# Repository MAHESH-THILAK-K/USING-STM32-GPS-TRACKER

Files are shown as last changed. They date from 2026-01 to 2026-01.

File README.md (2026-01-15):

# 📌 Project Overview

STM32-GPS-TRACKER is a compact, reliable, and industry-oriented GPS tracking system built around an **STM32 microcontroller** and the **SIM808 GSM/GPS module**. The system enables **real-time location tracking** and **cellular data transmission** for IoT and telemetry applications such as vehicle tracking, asset monitoring, and remote sensing.

The schematic and PCB are designed with **strong power integrity, EMI control, and manufacturability**, targeting a **4-layer PCB** suitable for real-world deployment.

---

## 🧩 System Architecture

| Block | Description |
| --- | --- |
| Power Input & Protection | Accepts 12 V input with fuse and surge protection |
| DC-DC Regulation | High-efficiency buck converter generates stable 3.3 V |
| Main Controller | STM32 microcontroller manages system logic |
| Communication Module | SIM808 provides GSM + GPS functionality |
| SIM Interface | SIM card socket with ESD protection |
| RF Section | U.FL connectors for GSM and GPS antennas |
| User Interface | Push buttons and status LEDs |
| Debug & Expansion | SWD and header pins for programming and I/O |

---

## 🔧 Core Controller – STM32 MCU

| Feature | Description |
| --- | --- |
| MCU | STM32 (ARM Cortex-M0 series) |
| Operating Voltage | 3.3 V |
| Clock Source | External crystal oscillator  |
| Programming | SWD (SWDIO, SWCLK, NRST) |
| Communication | UART interface to SIM808 |
| Control Signals | SIM808 PWRKEY, RESET |
| Indicators | Status LEDs via GPIO |

The STM32 acts as the **central controller**, handling GSM commands, GPS data processing, and system coordination.

---

## 📡 GSM/GPS Communication – SIM808

| Feature | Description |
| --- | --- |
| Module | SIM808 GSM + GPS |
| GSM | Cellular data communication |
| GPS | Satellite-based positioning |
| Interface | UART (TX/RX) |
| Control | Dedicated PWRKEY and RESET lines |
| Antennas  | Separate GSM and GPS U.FL connectors |

The SIM808 enables **accurate positioning** and **wide-area data transmission**, making the system suitable for mobile and remote applications.

---

## 🔋 Power Design

| Feature | Description |
| --- | --- |
| Input Voltage | 12 V DC |
| Regulator | TPS5430 buck converter |
| Output | 3.3 V regulated rail |
| Filtering | Bulk + ceramic decoupling capacitors |
| Protection | Fuse and transient suppression |

The switching regulator is designed to handle **high current bursts** from GSM transmission while maintaining voltage stability.

---

## 🛡️ SIM Card & Protection

| Feature | Description |
| --- | --- |
| SIM Socket | Standard SIM interface |
| Signal Conditioning | Series resistors |
| ESD Protection | Dedicated ESD diode array |
| Decoupling | Local capacitor for SIM supply |

This ensures **reliable SIM operation** and protection against electrostatic discharge.

---

## 📶 RF & Antenna Design

| Feature | Description |
| --- | --- |
| GSM Antenna | U.FL connector |
| GPS Antenna | U.FL connector |
| Grounding | Proper RF grounding and isolation |
| Layout Intent | Antenna keep-out zones respected  |

Designed to ensure **clean RF performance** and reduced interference.

---

## 🧪 PCB Design (4-Layer Optimized)

| Layer | Purpose |
| --- | --- |
| Top | Components and signal routing |
| Inner-1 | Solid GND plane |
| Inner-2 | 3.3 V power plane |
| Bottom  | Signal routing |

Benefits:

* Low impedance power delivery
* Reduced EMI
* Stable GSM/GPS performance
* Improved thermal and electrical reliability

## 🚀 Engineering Notes

* Designed for **4-layer PCB manufacturing**
* Robust power integrity for GSM current spikes
* EMI-aware grounding and routing
* Modular and expandable design
* Suitable for academic, hobby, and industry use

---

## 👤 Author

**MAHESH THILAK (MTK)**
Embedded Systems | PCB Design | IoT | Robotics

---

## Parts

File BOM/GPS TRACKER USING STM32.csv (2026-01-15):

Reference | Qty | Value | DNP | Exclude from BOM | Exclude from Board | Footprint | Datasheet
C1 | 1 | 100u |  |  |  | Capacitor_SMD:C_0603_1608Metric_Pad1.08x0.95mm_HandSolder | ~
C2 | 1 | 33p |  |  |  | Capacitor_SMD:C_0603_1608Metric_Pad1.08x0.95mm_HandSolder | ~
C3 | 1 | 10p |  |  |  | Capacitor_SMD:C_0603_1608Metric_Pad1.08x0.95mm_HandSolder | ~
C4 | 1 | 10u |  |  |  | Capacitor_SMD:C_0603_1608Metric_Pad1.08x0.95mm_HandSolder | ~
C5,C15 | 2 | 4u7 |  |  |  | Capacitor_SMD:C_0603_1608Metric_Pad1.08x0.95mm_HandSolder | ~
C6 | 1 | 22p |  |  |  | Capacitor_SMD:C_0603_1608Metric_Pad1.08x0.95mm_HandSolder | ~
C7 | 1 | 10n |  |  |  | Capacitor_SMD:C_0603_1608Metric_Pad1.08x0.95mm_HandSolder | ~
C8,C10 | 2 | 1u |  |  |  | Capacitor_SMD:C_0603_1608Metric_Pad1.08x0.95mm_HandSolder | ~
C9 | 1 | 220u |  |  |  | Capacitor_Tantalum_SMD:CP_EIA-7343-15_Kemet-W | ~
C11 | 1 | 220u |  |  |  | Capacitor_SMD:C_0603_1608Metric_Pad1.08x0.95mm_HandSolder | ~
C12,C14,C16,C17,C18,C19 | 6 | 100n |  |  |  | Capacitor_SMD:C_0603_1608Metric_Pad1.08x0.95mm_HandSolder | ~
C13 | 1 | 30p |  |  |  | Capacitor_SMD:C_0603_1608Metric_Pad1.08x0.95mm_HandSolder | ~
D1 | 1 | D_Zener |  |  |  | Diode_SMD:D_0805_2012Metric | ~
D2 | 1 | B340 |  |  |  | Diode_SMD:D_SMC | http://www.jameco.com/Jameco/Products/ProdDS/1538777.pdf
D3,D4,D5 | 3 | LED |  |  |  | LED_SMD:LED_0201_0603Metric | ~
F1 | 1 | Fuse 2.5A |  |  |  | Fuse:Fuse_0402_1005Metric | ~
GPS1,GSM1 | 2 | U.FL-R-SMT-1 |  |  |  | Library:U.FL-R-SMT-1
H1,H2,H3,H4 | 4 | MountingHole_Pad |  | Excluded from BOM |  | MountingHole:MountingHole_2.5mm_Pad_Via | ~
J2 | 1 | LEFT HEADER PINS |  |  |  | Connector_PinHeader_2.54mm:PinHeader_1x08_P2.54mm_Vertical | ~
J3 | 1 | RIGHT HEADER PINS |  |  |  | Connector_PinHeader_2.54mm:PinHeader_1x08_P2.54mm_Vertical | ~
J4 | 1 | 693010020611 |  |  |  | Library:693010020611
L1 | 1 | L_Iron |  |  |  | Inductor_SMD:L_10.4x10.4_H4.8 | ~
P1 | 1 | 282837-2 |  |  |  | Library:TE_282837-2
Q1 | 1 | AO3407A |  |  |  | Library:SOT65P210X110-6N
R1 | 1 | 4K7 |  |  |  | Resistor_SMD:R_0201_0603Metric_Pad0.64x0.40mm_HandSolder | ~
R2,R3,R4,R10 | 4 | 10K |  |  |  | Resistor_SMD:R_0201_0603Metric_Pad0.64x0.40mm_HandSolder | ~
R5 | 1 | 8K2 |  |  |  | Resistor_SMD:R_0201_0603Metric_Pad0.64x0.40mm_HandSolder | ~
R6,R8,R12,R13 | 4 | 1K5 |  |  |  | Resistor_SMD:R_0201_0603Metric_Pad0.64x0.40mm_HandSolder | ~
R7 | 1 | 2K7 |  |  |  | Resistor_SMD:R_0201_0603Metric_Pad0.64x0.40mm_HandSolder | ~
R9 | 1 | 100K |  |  |  | Resistor_SMD:R_0201_0603Metric_Pad0.64x0.40mm_HandSolder | ~
R11 | 1 | 1K |  |  |  | Resistor_SMD:R_0201_0603Metric_Pad0.64x0.40mm_HandSolder | ~
SW1,SW2 | 2 | SW_Push |  |  |  | Button_Switch_SMD:SW_Push_1P1T_NO_CK_KSC6xxJ | ~
U1 | 1 | SIM808 |  |  |  | Library:XCVR_SIM808
U2 | 1 | TPS5430DDA |  |  |  | Package_SO:TI_SO-PowerPAD-8_ThermalVias | http://www.ti.com/lit/ds/symlink/tps5430.pdf
U3 | 1 | SMF05CT1G |  |  |  | Library:SOT65P210X110-6N
U4 | 1 | STM32F030C8Tx |  |  |  | Package_QFP:LQFP-48_7x7mm_P0.5mm | https://www.st.com/resource/en/datasheet/stm32f030c8.pdf
Y1 | 1 | Crystal |  |  |  | Crystal:Crystal_SMD_5032-2Pin_5.0x3.2mm | ~

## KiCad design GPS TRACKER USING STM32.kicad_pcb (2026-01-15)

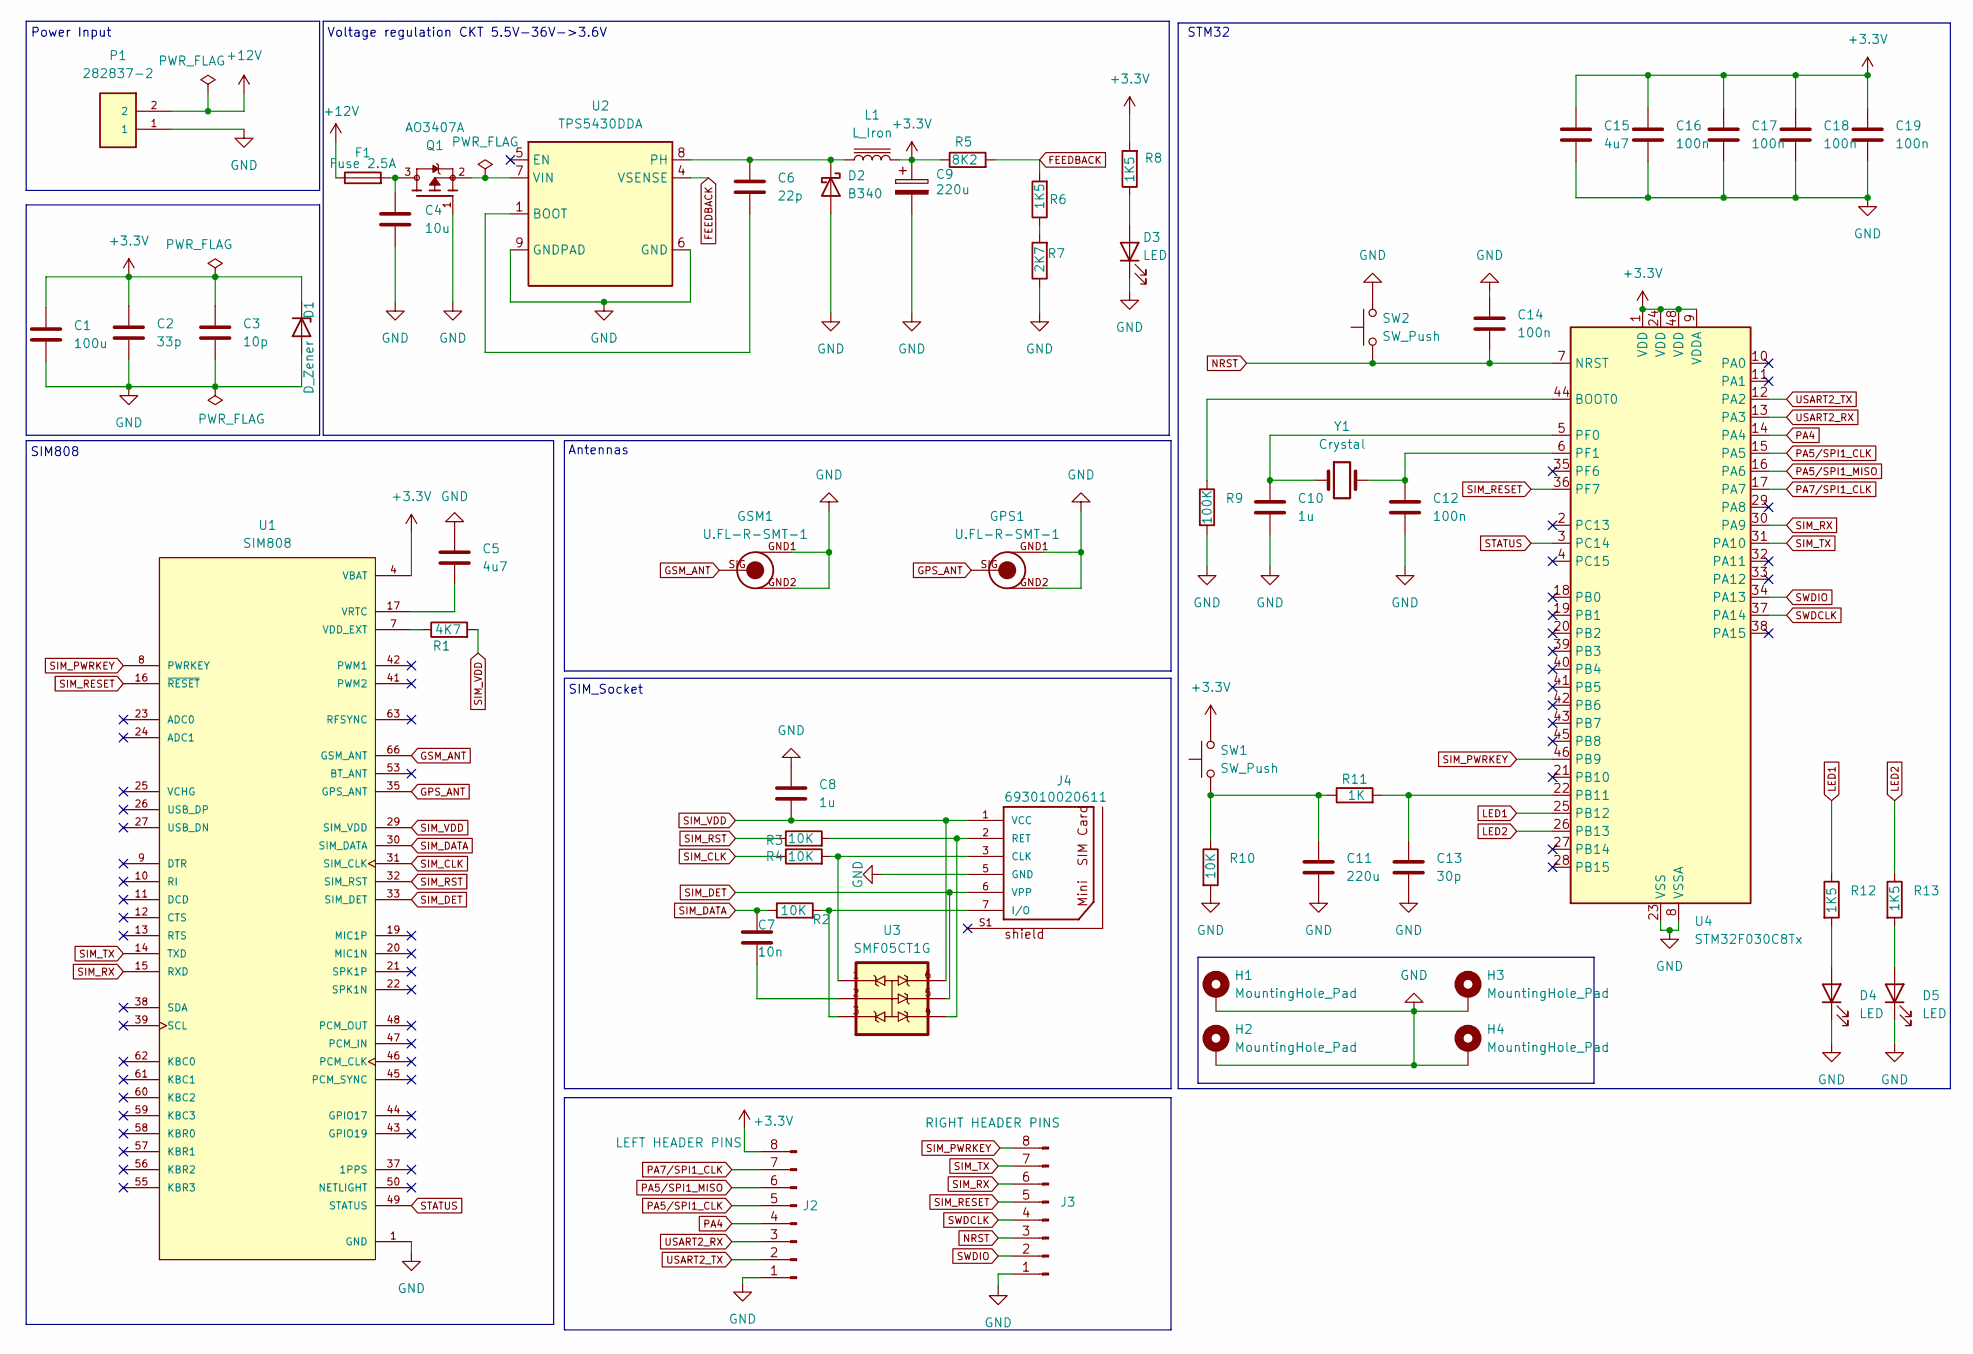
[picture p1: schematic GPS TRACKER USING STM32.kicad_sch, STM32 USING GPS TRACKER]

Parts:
C1: 100u; C_0603_1608Metric_Pad1.08x0.95mm_HandSolder
C2: 33p; C_0603_1608Metric_Pad1.08x0.95mm_HandSolder
C3: 10p; C_0603_1608Metric_Pad1.08x0.95mm_HandSolder
C4: 10u; C_0603_1608Metric_Pad1.08x0.95mm_HandSolder
C5, C15: 4u7; C_0603_1608Metric_Pad1.08x0.95mm_HandSolder
C6: 22p; C_0603_1608Metric_Pad1.08x0.95mm_HandSolder
C7: 10n; C_0603_1608Metric_Pad1.08x0.95mm_HandSolder
C8, C10: 1u; C_0603_1608Metric_Pad1.08x0.95mm_HandSolder
C9: 220u; CP_EIA-7343-15_Kemet-W
C11: 220u; C_0603_1608Metric_Pad1.08x0.95mm_HandSolder
C12, C14, C16, C17, C18, C19: 100n; C_0603_1608Metric_Pad1.08x0.95mm_HandSolder
C13: 30p; C_0603_1608Metric_Pad1.08x0.95mm_HandSolder
D1: D_Zener; D_0805_2012Metric
D2: B340; D_SMC
D3, D4, D5: LED; LED_0201_0603Metric
F1: Fuse 2.5A; Fuse_0402_1005Metric
GPS1: U.FL-R-SMT-1
GSM1: U.FL-R-SMT-1
H1, H2, H3, H4: MountingHole_Pad; MountingHole_2.5mm_Pad_Via
J2: LEFT HEADER PINS; PinHeader_1x08_P2.54mm_Vertical
J3: RIGHT HEADER PINS; PinHeader_1x08_P2.54mm_Vertical
J4: 693010020611
L1: L_Iron; L_10.4x10.4_H4.8
P1: 282837-2; TE_282837-2; PARTREV G3
Q1: AO3407A; SOT65P210X110-6N; PARTREV 5
R1: 4K7; R_0201_0603Metric_Pad0.64x0.40mm_HandSolder
R2, R3, R4, R10: 10K; R_0201_0603Metric_Pad0.64x0.40mm_HandSolder
R5: 8K2; R_0201_0603Metric_Pad0.64x0.40mm_HandSolder
R6, R8, R12, R13: 1K5; R_0201_0603Metric_Pad0.64x0.40mm_HandSolder
R7: 2K7; R_0201_0603Metric_Pad0.64x0.40mm_HandSolder
R9: 100K; R_0201_0603Metric_Pad0.64x0.40mm_HandSolder
R11: 1K; R_0201_0603Metric_Pad0.64x0.40mm_HandSolder
SW1, SW2: SW_Push; SW_Push_1P1T_NO_CK_KSC6xxJ
U1: SIM808; XCVR_SIM808; PARTREV 1.03
U2: TPS5430DDA; TI_SO-PowerPAD-8_ThermalVias
U3: SMF05CT1G; SOT65P210X110-6N
U4: STM32F030C8Tx; LQFP-48_7x7mm_P0.5mm
Y1: Crystal; Crystal_SMD_5032-2Pin_5.0x3.2mm

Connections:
+3.3V: C1.1, C2.1, C3.1, C9.1, C15.1, C16.1, C17.1, C18.1, C19.1, D1.1 (K), J2.8, L1.2, R5.1, R8.2, SW1.2, U1.4 (VBAT), U1.5 (VBAT), U1.6 (VBAT), U4.1 (VDD), U4.9 (VDDA), U4.24 (VDD), U4.48 (VDD)
+12V: F1.1, P1.2
FEEDBACK: R5.2, R6.2, U2.4 (VSENSE)
GND: C1.2, C2.2, C3.2, C4.2, C5.1, C8.1, C9.2, C10.2, C11.2, C12.2, C13.2, C14.1, C15.2, C16.2, C17.2, C18.2, C19.2, D1.2 (A), D2.2 (A), D3.1 (K), D4.1 (K), D5.1 (K), GPS1.GND1, GPS1.GND2, GSM1.GND1, GSM1.GND2, H1.1, H2.1, H3.1, H4.1, J2.1, J3.1, J4.5 (GND), P1.1, Q1.1, R7.1, R9.2, R10.2, SW2.2, U1.1 (GND), U1.2 (GND), U1.3 (GND), U1.18 (GND), U1.28 (GND), U1.34 (GND), U1.36 (GND), U1.40 (GND), U1.51 (GND), U1.52 (GND), U1.54 (GND), U1.64 (GND), U1.65 (GND), U1.67 (GND), U1.68 (GND), U2.6 (GND), U2.9 (GNDPAD), U4.8 (VSSA), U4.23 (VSS), U4.47 (VSS)
GPS_ANT: GPS1.SIG, U1.35 (GPS_ANT)
GSM_ANT: GSM1.SIG, U1.66 (GSM_ANT)
LED1: R12.1, U4.25 (PB12)
LED2: R13.1, U4.26 (PB13)
NRST: C14.2, J3.3, SW2.1, U4.7 (NRST)
unnamed: C4.1, F1.2, Q1.3
unnamed: C7.2, U3.2
unnamed: C11.1, R10.1, R11.1, SW1.1
unnamed: C6.1, D2.1 (K), L1.1, U2.8 (PH)
unnamed: D3.2 (A), R8.1
unnamed: D4.2 (A), R12.2
unnamed: D5.2 (A), R13.2
unnamed: J4.3 (CLK), R4.2, U3.1
unnamed: J4.7 (I/O), R2.2, U3.3
unnamed: J4.2 (RET), R3.2, U3.4
unnamed: R6.1, R7.2
unnamed: R1.1, U1.7 (VDD_EXT)
unnamed: C5.2, U1.17 (VRTC)
unnamed: C6.2, U2.1 (BOOT)
unnamed: Q1.2, U2.7 (VIN)
unnamed: R9.1, U4.44 (BOOT0)
unnamed: C13.1, R11.2, U4.22 (PB11)
unnamed: C10.1, U4.5 (PF0), Y1.1
unnamed: C12.1, U4.6 (PF1), Y1.2
PA4: J2.4, U4.14 (PA4)
PA5/SPI1_CLK: J2.5, U4.15 (PA5)
PA5/SPI1_MISO: J2.6, U4.16 (PA6)
PA7/SPI1_CLK: J2.7, U4.17 (PA7)
SIM_CLK: R4.1, U1.31 (SIM_CLK)
SIM_DATA: C7.1, R2.1, U1.30 (SIM_DATA)
SIM_DET: J4.6 (VPP), U1.33 (SIM_DET), U3.5
SIM_PWRKEY: J3.8, U1.8 (PWRKEY), U4.46 (PB9)
SIM_RESET: J3.5, U1.16 (~RESET), U4.36 (PF7)
SIM_RST: R3.1, U1.32 (SIM_RST)
SIM_RX: J3.6, U1.15 (RXD), U4.30 (PA9)
SIM_TX: J3.7, U1.14 (TXD), U4.31 (PA10)
SIM_VDD: C8.2, J4.1 (VCC), R1.2, U1.29 (SIM_VDD), U3.6
STATUS: U1.49 (STATUS), U4.3 (PC14)
SWDCLK: J3.4, U4.37 (PA14)
SWDIO: J3.2, U4.34 (PA13)
USART2_RX: J2.3, U4.13 (PA3)
USART2_TX: J2.2, U4.12 (PA2)

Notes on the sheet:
SIM_Socket
SIM808
Power Input
STM32
Voltage regulation CKT 5.5V-36V->3.6V
Antennas

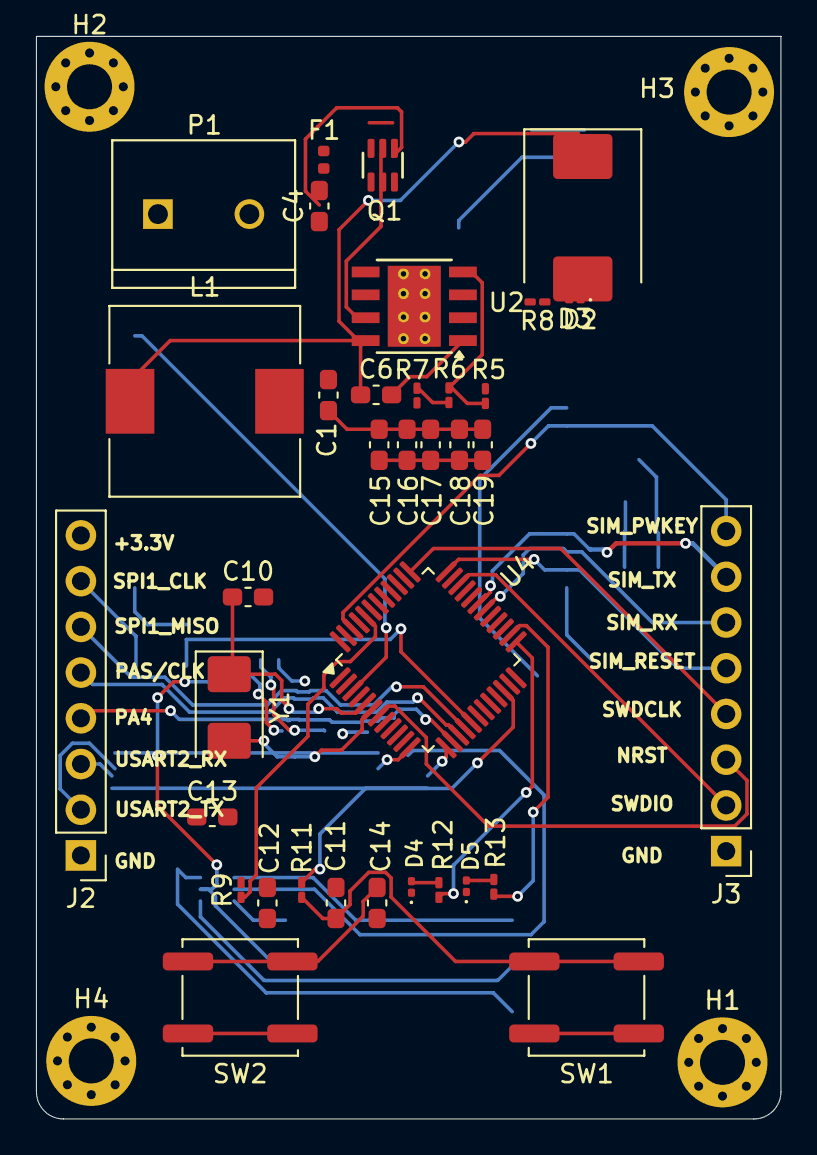
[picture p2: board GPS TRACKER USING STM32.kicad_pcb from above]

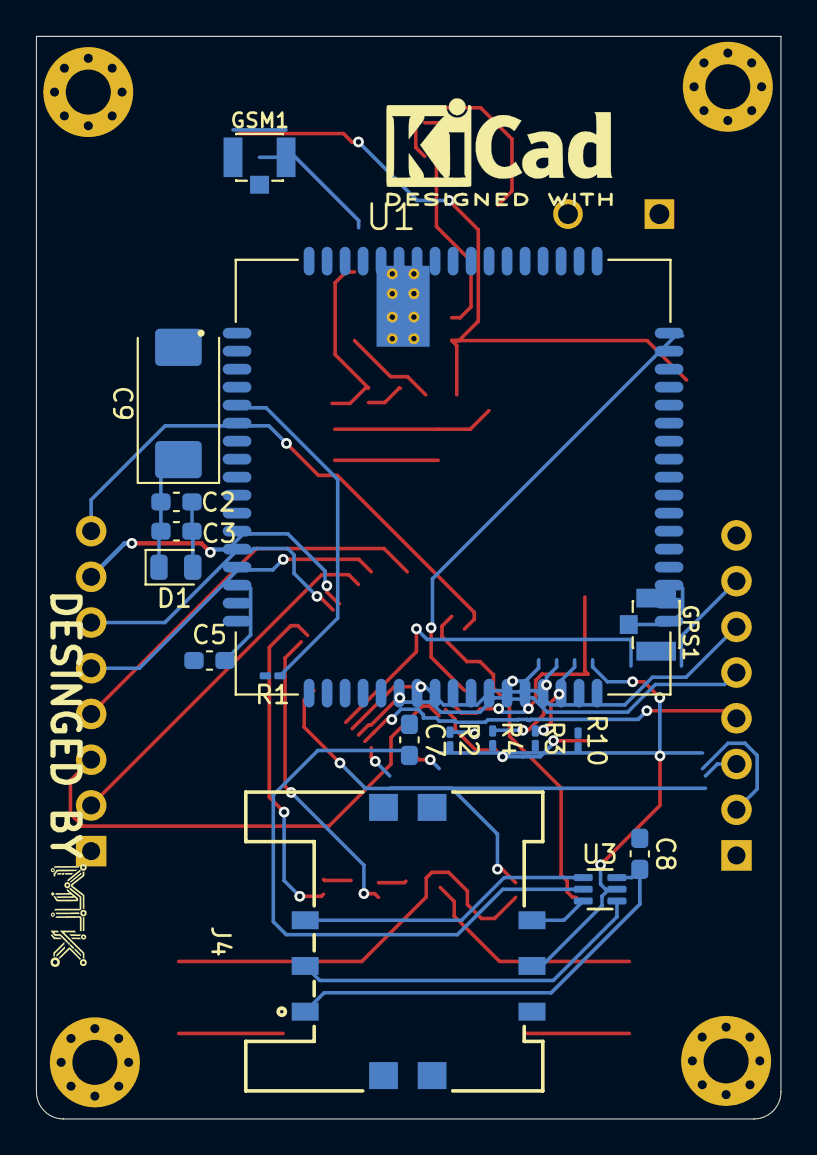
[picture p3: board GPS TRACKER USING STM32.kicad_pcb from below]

Board: 4 copper layers, 41.4 x 60.1 mm, 57 parts (17 on the bottom side), 46 nets.

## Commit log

2026-04-24 Create Gerber
2026-04-24 Create Gerber
